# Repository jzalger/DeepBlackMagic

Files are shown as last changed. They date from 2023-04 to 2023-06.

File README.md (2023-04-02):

DeepBlackMagic
==============



This project contains the control software for a custom underwater camera system based on the BlackMagic Micro Cinema Camera (BMMCC).

The controller converts basic momentary control such as recording start/stop and aperature adustments and sends it to the camera via SBUS.

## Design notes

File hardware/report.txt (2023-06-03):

Info: Updated footprint C20 (Capacitor_SMD:C_0402_1005Metric): : (no changes)
Info: Updated footprint C10 (Capacitor_SMD:C_1206_3216Metric): : (no changes)
Info: Updated footprint H4 (MountingHole:MountingHole_2.2mm_M2_DIN965_Pad): : (no changes)
Info: Updated footprint L3 (Inductor_SMD:L_0402_1005Metric): : (no changes)
Info: Updated footprint H2 (MountingHole:MountingHole_2.2mm_M2_DIN965_Pad): : (no changes)
Info: Updated footprint R5 (Resistor_SMD:R_0402_1005Metric): : (no changes)
Info: Updated footprint R13 (Resistor_SMD:R_0402_1005Metric): : (no changes)
Info: Updated footprint J6 (TerminalBlock_MetzConnect:TerminalBlock_MetzConnect_Type086_RT03402HBLC_1x02_P3.81mm_Horizontal): : (no changes)
Info: Updated footprint J1 (Connector_USB:USB_C_Receptacle_G-Switch_GT-USB-7010ASV): : (no changes)
Info: Updated footprint C9 (Capacitor_SMD:C_1206_3216Metric): : (no changes)
Info: Updated footprint R2 (Resistor_SMD:R_0603_1608Metric): : (no changes)
Info: Updated footprint Q1 (Package_TO_SOT_SMD:SOT-363_SC-70-6): : (no changes)
Info: Updated footprint D4 (LED_SMD:LED_0603_1608Metric): : (no changes)
Info: Updated footprint R16 (Resistor_SMD:R_0402_1005Metric): : (no changes)
Info: Updated footprint R1 (Resistor_SMD:R_0603_1608Metric): : (no changes)
Info: Updated footprint D5 (Diode_SMD:D_SOD-323): : (no changes)
Info: Updated footprint J3 (TerminalBlock_MetzConnect:TerminalBlock_MetzConnect_Type086_RT03402HBLC_1x02_P3.81mm_Horizontal): : (no changes)
Info: Updated footprint C17 (Capacitor_SMD:C_0805_2012Metric): : (no changes)
Info: Updated footprint C15 (Capacitor_SMD:C_0805_2012Metric): : (no changes)
Info: Updated footprint D3 (Diode_SMD:D_SOD-123F): : (no changes)
Info: Updated footprint C16 (Capacitor_SMD:C_0805_2012Metric): : (no changes)
Info: Updated footprint R12 (Resistor_SMD:R_0402_1005Metric): : (no changes)
Info: Updated footprint D9 (Diode_SMD:D_SOD-323): : (no changes)
Info: Updated footprint C8 (Capacitor_SMD:C_1206_3216Metric): : (no changes)
Info: Updated footprint R11 (Resistor_SMD:R_0402_1005Metric): : (no changes)
Info: Updated footprint D8 (Diode_SMD:D_SOD-323): : (no changes)
Info: Updated footprint J5 (TerminalBlock_MetzConnect:TerminalBlock_MetzConnect_Type086_RT03402HBLC_1x02_P3.81mm_Horizontal): : (no changes)
Info: Updated footprint C6 (Capacitor_SMD:C_1206_3216Metric): : (no changes)
Info: Updated footprint C12 (Capacitor_SMD:C_1206_3216Metric): : (no changes)
Info: Updated footprint D7 (Diode_SMD:D_SOD-323): : (no changes)
Info: Updated footprint H3 (MountingHole:MountingHole_2.2mm_M2_DIN965_Pad): : (no changes)
Info: Updated footprint U1 (RF_Module:ESP32-WROOM-32): : (no changes)
Info: Updated footprint J2 (footprints:AMASS_XT60PW-M): : (no changes)
Info: Updated footprint Q2 (Package_TO_SOT_SMD:SOT-363_SC-70-6): : (no changes)
Info: Updated footprint U3 (footprints:DSC_10_TEX): : (no changes)
Info: Updated footprint D1 (Diode_SMD:D_SOD-923): : (no changes)
Info: Updated footprint C1 (Capacitor_SMD:C_0402_1005Metric): : (no changes)
Info: Updated footprint C19 (Capacitor_SMD:C_0603_1608Metric): : (no changes)
Info: Updated footprint L1 (Inductor_SMD:L_Bourns_SRP7028A_7.3x6.6mm): : (no changes)
Info: Updated footprint SW1 (Resistor_SMD:R_0402_1005Metric): : (no changes)
Info: Updated footprint U6 (Package_TO_SOT_SMD:SOT-23-5): : (no changes)
Info: Updated footprint D2 (Diode_SMD:D_SOD-923): : (no changes)
Info: Updated footprint C3 (Capacitor_SMD:C_1206_3216Metric): : (no changes)
Info: Updated footprint R9 (Resistor_SMD:R_0402_1005Metric): : (no changes)
Info: Updated footprint F1 (Fuse:Fuse_1206_3216Metric): : (no changes)
Info: Updated footprint D6 (Diode_SMD:D_SOD-323): : (no changes)
Info: Updated footprint J4 (TerminalBlock_MetzConnect:TerminalBlock_MetzConnect_Type086_RT03402HBLC_1x02_P3.81mm_Horizontal): : (no changes)
Info: Updated footprint C11 (Capacitor_SMD:C_1206_3216Metric): : (no changes)
Info: Updated footprint R10 (Resistor_SMD:R_0603_1608Metric): : (no changes)
Info: Updated footprint R3 (Resistor_SMD:R_0402_1005Metric): : (no changes)
Info: Updated footprint U5 (Package_TO_SOT_SMD:SOT-23-6): : (no changes)
Info: Updated footprint R4 (Resistor_SMD:R_0402_1005Metric): : (no changes)
Info: Updated footprint U2 (Package_DFN_QFN:QFN-24-1EP_4x4mm_P0.5mm_EP2.6x2.6mm): : (no changes)
Info: Updated footprint J8 (TerminalBlock_MetzConnect:TerminalBlock_MetzConnect_Type086_RT03402HBLC_1x02_P3.81mm_Horizontal): : (no changes)
Info: Updated footprint D10 (Diode_SMD:D_SOD-123F): : (no changes)
Info: Updated footprint C18 (Capacitor_SMD:C_0805_2012Metric): : (no changes)
Info: Updated footprint C5 (Capacitor_SMD:C_1206_3216Metric): : (no changes)
Info: Updated footprint C4 (Capacitor_SMD:C_1206_3216Metric): : (no changes)
Info: Updated footprint R14 (Resistor_SMD:R_0402_1005Metric): : (no changes)
Info: Updated footprint L2 (Inductor_SMD:L_Bourns_SRP7028A_7.3x6.6mm): : (no changes)
Info: Updated footprint R15 (Resistor_SMD:R_0402_1005Metric): : (no changes)
Info: Updated footprint J7 (TerminalBlock_4Ucon:TerminalBlock_4Ucon_1x06_P3.50mm_Horizontal): : (no changes)
Info: Updated footprint R7 (Resistor_SMD:R_0402_1005Metric): : (no changes)
Info: Updated footprint C14 (Capacitor_SMD:C_0805_2012Metric): : (no changes)
Info: Updated footprint H1 (MountingHole:MountingHole_2.2mm_M2_DIN965_Pad): : (no changes)
Info: Updated footprint C2 (Capacitor_SMD:C_1206_3216Metric): : (no changes)
Info: Updated footprint R8 (Resistor_SMD:R_0603_1608Metric): : (no changes)
Info: Updated footprint U4 (footprints:DSC_10_TEX): : (no changes)
Info: Updated footprint C13 (Capacitor_SMD:C_0402_1005Metric): : (no changes)
Info: Updated footprint R6 (Resistor_SMD:R_0603_1608Metric): : (no changes)

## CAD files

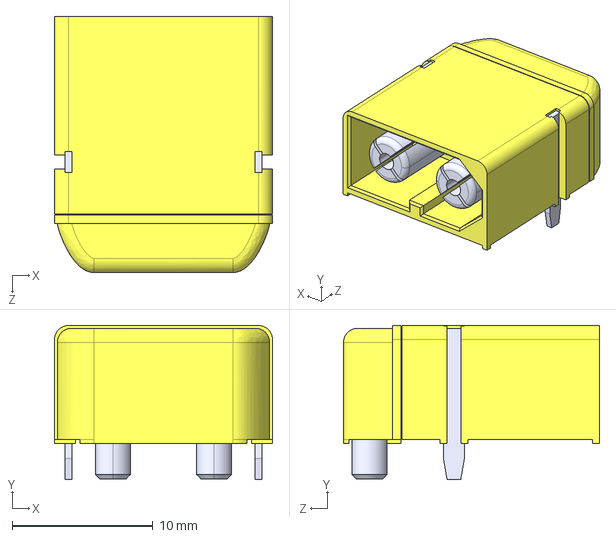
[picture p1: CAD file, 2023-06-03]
hardware/footprints/XT60PW-M.step
15.5 x 11.0 x 18.2 mm

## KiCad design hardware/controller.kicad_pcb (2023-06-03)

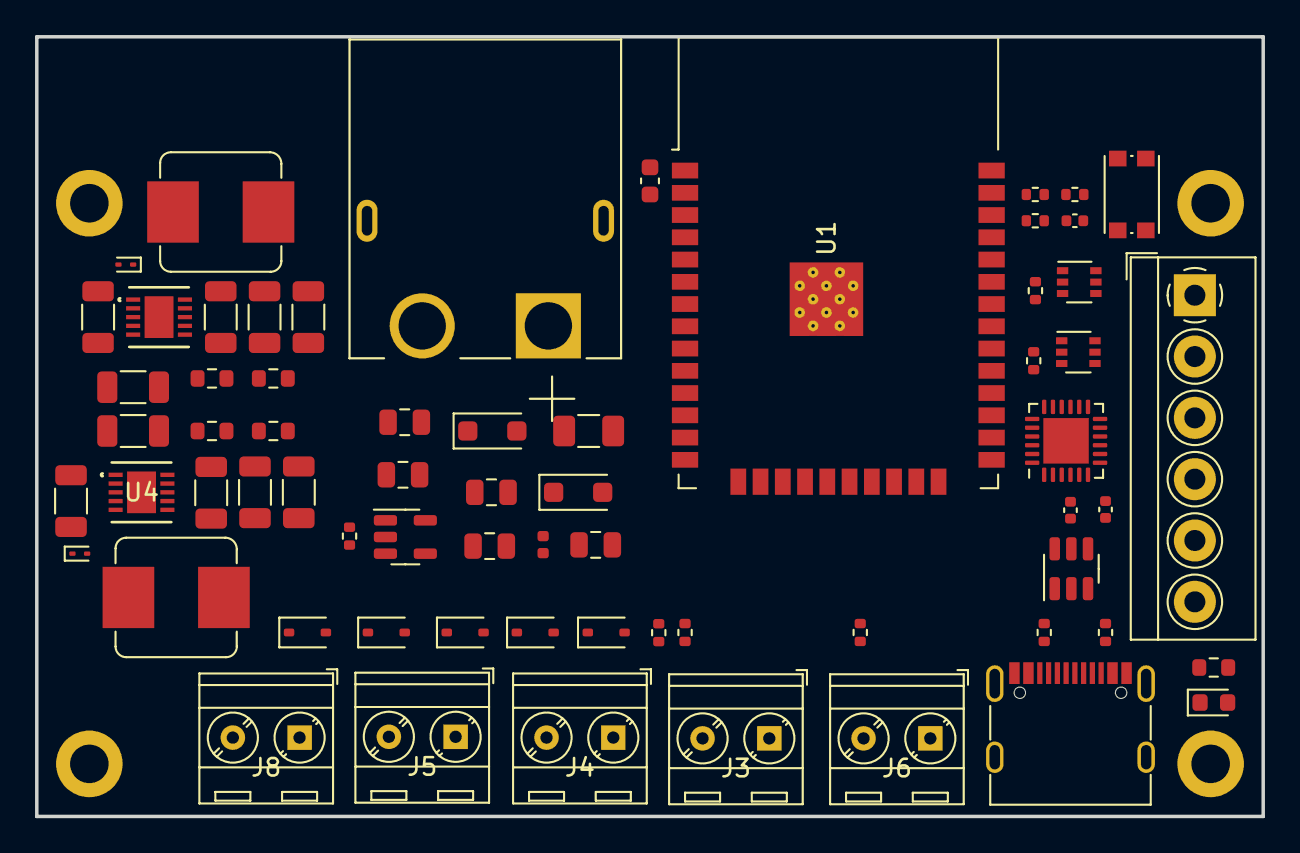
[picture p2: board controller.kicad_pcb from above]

Board: 4 copper layers, 70.0 x 44.5 mm, 70 parts (0 on the bottom side), 43 nets, no tracks yet.

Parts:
C1: 1uF; C_0402_1005Metric
C2, C3, C4, C5: 22uF; C_1206_3216Metric
C6, C8: 0.1uF; C_1206_3216Metric
C9, C11: 10uF; C_1206_3216Metric
C10, C12: 0.18uF; C_1206_3216Metric
C13: 100nF; C_0402_1005Metric
C14, C15, C18: 1uF; C_0805_2012Metric
C16, C17: 10uF; C_0805_2012Metric
C19: 10uF; C_0603_1608Metric
C20: 10uF; C_0402_1005Metric
D1, D2: 0.32V; D_SOD-923
D3, D10: MBR120; D_SOD-123F
D4: LED; LED_0603_1608Metric
D5, D6, D7, D8, D9: PESD3V3L1BA; D_SOD-323
F1: 2A; Fuse_1206_3216Metric
H1, H2, H3, H4: MountingHole_Pad; MountingHole_2.2mm_M2_DIN965_Pad
J1: USB_C_Receptacle_USB2.0; USB_C_Receptacle_G-Switch_GT-USB-7010ASV
J2: XT60PW-M; AMASS_XT60PW-M
J3: 12V; TerminalBlock_MetzConnect_Type086_RT03402HBLC_1x02_P3.81mm_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
J4: SBUS; TerminalBlock_MetzConnect_Type086_RT03402HBLC_1x02_P3.81mm_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
J5: BTN1; TerminalBlock_MetzConnect_Type086_RT03402HBLC_1x02_P3.81mm_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
J6: SW; TerminalBlock_MetzConnect_Type086_RT03402HBLC_1x02_P3.81mm_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
J7: DNP; TerminalBlock_4Ucon_1x06_P3.50mm_Horizontal
J8: BTN0; TerminalBlock_MetzConnect_Type086_RT03402HBLC_1x02_P3.81mm_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
L1, L2: 3.3uH; L_Bourns_SRP7028A_7.3x6.6mm
L3: 10nH; L_0402_1005Metric
Q1, Q2: MMDT2222A; SOT-363_SC-70-6
R1: 1k; R_0603_1608Metric
R2: 1.02k; R_0603_1608Metric
R3, R4, R5, R7, R11, R14, R15: 10k; R_0402_1005Metric
R6: 11k; R_0603_1608Metric
R8: 2.32k; R_0603_1608Metric
R9: 100k; R_0402_1005Metric
R10: 300; R_0603_1608Metric
R12, R13: 5k1; R_0402_1005Metric
R16: 20k; R_0402_1005Metric
SW1: SW_SPST; SW_Push_1P1T_NO_CK_KMR2
U1: ESP32-WROOM-32
U2: CP2104; QFN-24-1EP_4x4mm_P0.5mm_EP2.6x2.6mm
U3, U4: LMR12020XSD/NOPB; DSC_10_TEX
U5: USBLC6-2SC6; SOT-23-6
U6: AP2112K-3.3; SOT-23-5

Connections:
+3.3V: C3.1, C5.1, C12.2, C17.1, C18.1, C19.1, C20.2, D4.2 (A), J7.1, J8.1, L2.1, R3.1, R8.2, R14.1, R15.1, U1.2 (VDD), U2.5 (VIO), U2.6 (VDD), U2.7 (REGIN), U6.5 (VOUT)
+12V: C2.1, C4.1, C10.2, J3.1, L1.1, R6.2
/MicroController/A0_REC: D6.2 (A2), J8.2, U1.11 (IO26)
/MicroController/A1_AUX_UP: D7.2 (A2), J5.1, U1.10 (IO25)
/MicroController/A5_AUX_DN: D8.2 (A2), J5.2, U1.26 (IO4)
/MicroController/DTR: Q1.1 (E1), R5.1, U2.23 (~DTR)
/MicroController/GPIO0: Q1.6 (C1), U1.25 (IO0)
/MicroController/GPIO2: J7.3, U1.24 (IO2)
/MicroController/IO12_A11: J7.6, U1.14 (IO12)
/MicroController/RESET: C1.1, Q2.6 (C1), R3.2, SW1.2 (B), U1.3 (EN)
/MicroController/RTS: Q2.1 (E1), R4.1, U2.19 (~RTS)
/MicroController/RXDO: U1.34 (RXD0/IO3), U2.21 (TXD)
/MicroController/SBUS_RX_H: D9.2 (A2), J4.1, R7.2
/MicroController/SBUS_RX_L: R7.1, R16.2, U1.27 (IO16)
/MicroController/SBUS_TX: D5.2 (A2), J4.2, U1.28 (IO17)
/MicroController/SCL: J7.4, R14.2, U1.36 (IO22)
/MicroController/SDA: J7.5, R15.2, U1.37 (IO23)
/MicroController/TXDO: U1.35 (TXD0/IO1), U2.20 (RXD)
/MicroController/USB_CON_D+: J1.A6 (D+), J1.B6 (D+), U5.3 (I/O2)
/MicroController/USB_CON_D-: J1.A7 (D-), J1.B7 (D-), U5.1 (I/O1)
/MicroController/USB_D+: U2.3 (D+), U5.4 (I/O2)
/MicroController/USB_D-: U2.4 (D-), U5.6 (I/O1)
/Power/3V_BUCK_SW: C8.1, D2.1 (K), L2.2, U4.1 (SW), U4.2 (SW)
/Power/3V_SW_FB: C12.1, R2.1, R8.1, U4.6 (FB)
/Power/12V_BUCK_SW: C6.1, D1.1 (K), L1.2, U3.1 (SW), U3.2 (SW)
/Power/12V_SW_FB: C10.1, R1.1, R6.1, U3.6 (FB)
/Power/PWR_ENABLE: R11.2, U3.4 (EN), U4.4 (EN)
GND: C1.2, C2.2, C3.2, C4.2, C5.2, C9.2, C11.2, C13.2, C14.2, C15.2, C16.2, C17.2, C18.2, C19.2, C20.1, D1.2 (A), D2.2 (A), D5.1 (A1), D6.1 (A1), D7.1 (A1), D8.1 (A1), D9.1 (A1), H1.1, H2.1, H3.1, H4.1, J1.A1 (GND), J1.A12 (GND), J1.B1 (GND), J1.B12 (GND), J1.S1 (SHIELD), J2.2 (-), J3.2, J7.2, R1.2, R2.2, R10.2, R12.1, R13.2, R16.1, SW1.1 (A), U1.1 (GND), U1.15 (GND), U1.38 (GND), U1.39 (GND), U2.2 (GND), U2.25 (GND), U3.7 (GND), U3.11 (EPAD), U4.7 (GND), U4.11 (EPAD), U5.2 (GND), U6.2 (GND)
unnamed: D3.2 (A), F1.1
unnamed: D4.1 (K), R10.1
unnamed: C14.1, D10.1 (K), L3.1
unnamed: J1.A5 (CC1), R12.2
unnamed: J1.B5 (CC2), R13.1
unnamed: F1.2, J2.1 (+)
unnamed: J6.2, R11.1
unnamed: Q1.2 (B1), R4.2
unnamed: Q2.2 (B1), R5.2
unnamed: C6.2, U3.3 (BOOST)
unnamed: C8.2, U4.3 (BOOST)
unnamed: R9.2, U6.3 (EN)
unnamed: C15.1, C16.1, L3.2, R9.1, U6.1 (VIN)
VBATT: C9.1, C11.1, D3.1 (K), J6.1, U3.8 (AVIN), U3.9 (PVIN), U3.10 (PVIN), U4.8 (AVIN), U4.9 (PVIN), U4.10 (PVIN)
VBUS: C13.1, D10.2 (A), J1.A4 (VBUS), J1.A9 (VBUS), J1.B4 (VBUS), J1.B9 (VBUS), U2.8 (VBUS), U5.5 (VBUS)

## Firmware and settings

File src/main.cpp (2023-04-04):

#include "main.h"

bfs::SbusTx sbus(&Serial1, SERIAL_RX_PIN, SERIAL_TX_PIN, true);

Button record_btn = {RECORD_PIN, false};
Button aux_up_btn = {AUX_UP_PIN, false};
Button aux_down_btn = {AUX_DOWN_PIN, false};
unsigned long button_time = 0;
unsigned long last_button_time = 0;

// #################################################################################

void IRAM_ATTR record_isr(){
  button_time = millis();
  if (button_time - last_button_time > 300){
    record_btn.pressed = true;
    last_button_time = button_time;
  }
}

void IRAM_ATTR aux_up_isr(){
  button_time = millis();
  if (button_time - last_button_time > 300){
    aux_up_btn.pressed = true;
    last_button_time = button_time;
  }
}

void IRAM_ATTR aux_down_isr(){
  button_time = millis();
  if (button_time - last_button_time > 300){
    aux_down_btn.pressed = true;
    last_button_time = button_time;
  }
}

// ###################################################################

void setup() {
  Serial.begin(115200);
  pinMode(RECORD_PIN, INPUT_PULLDOWN);
  attachInterrupt(RECORD_PIN, record_isr, HIGH);
  pinMode(AUX_UP_PIN, INPUT_PULLDOWN);
  attachInterrupt(AUX_UP_PIN, aux_up_isr, HIGH);
  pinMode(AUX_DOWN_PIN, INPUT_PULLDOWN);
  attachInterrupt(AUX_DOWN_PIN, aux_down_isr, HIGH);
  sbus.Begin();
}

void loop() {
  if (record_btn.pressed) {
    toggle_record();
    record_btn.pressed = false;
  }
  if (aux_up_btn.pressed) {
    increase_fstop();
    aux_up_btn.pressed = false;
  }
  if (aux_down_btn.pressed) {
    decrease_fstop();
    aux_down_btn.pressed = false;
  }
}

// ################################################################################

void send_sbus(int ch, int value) {
  //Writes the value for a specific channel to the SBUS
  data.ch[ch] = value;
  sbus.data(data);
  sbus.Write();
}

void toggle_sbus(int ch, int value){
    send_sbus(ch, SBUS_MID);
    vTaskDelay(SBUS_DELAY);
    send_sbus(ch, value);
    vTaskDelay(SBUS_DELAY);
    send_sbus(ch, SBUS_MID);
}

void toggle_record() {
  // Starts or stops camera recording
  if (recording == false){
    toggle_sbus(SBUS_REC_CH, SBUS_HIGH);
    recording = true;
  } else {
    toggle_sbus(SBUS_REC_CH, SBUS_MIN);
    recording = false;
  }
}

void increase_fstop() {
  // Increases the f-stop (closes the aperature) by one stop
  if (iris_index < 8) {
    ++iris_index;
    send_sbus(SBUS_IRIS_CH, apertures[iris_index]);
    vTaskDelay(SBUS_DELAY);
  }
}

void decrease_fstop() {
  // Decreases the f-stop (opens the aperature) by one stop
    if (iris_index > 0) {
    --iris_index;
    send_sbus(SBUS_IRIS_CH, apertures[iris_index]);
    vTaskDelay(SBUS_DELAY);
  }
}

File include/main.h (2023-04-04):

#include <Arduino.h>
#include <HardwareSerial.h>
#include "sbus.h"

#define RECORD_PIN A0
#define AUX_UP_PIN A1
#define AUX_DOWN_PIN A5

#define SBUS_HIGH 2046
#define SBUS_MID 1024
#define SBUS_MIN 0
#define SBUS_DELAY 6
#define SBUS_INC 160
#define SERIAL_RX_PIN 16
#define SERIAL_TX_PIN 17

#define SBUS_REC_CH 0
#define SBUS_IRIS_CH 1

bool recording = false;
uint8_t iris_index = 0;

struct Button {
  const uint8_t pin;
  bool pressed;
};

bfs::SbusData data;

// Equates to [f1.8, f2, f2.8, f4, f5.6, f8, f11, f16, f22]
uint16_t apertures[9] = {300, 460, 620, 780, 940, 1100, 1260, 1420, 1600};

void IRAM_ATTR record_isr();
void IRAM_ATTR aux_up_isr();
void IRAM_ATTR aux_down_isr();

void toggle_sbus(int ch, int value);
void toggle_record();
void increase_fstop();
void decrease_fstop();

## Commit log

2023-04-01 sbus and button implementation
2023-04-02 Changed GPIO pins and improved button press stability.
    [main.cpp]
2023-04-02 Fixed SBUS channel alignment
    [main.cpp]
2023-04-03 Fixed SBUS issues with camera [not tested]
    [main.cpp, main.h]
2023-04-04 Working camera control
2023-05-20 Initial hardware files
    [controller.kicad_sch]
2023-05-20 Rouging out schematic
    [controller.kicad_sch]
2023-06-03 Schematic updates and initial layout
    [PCB_NEW_PCB_2023-05-23.kicad_pcb, XT60PW-M.step, controller.kicad_pcb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]
